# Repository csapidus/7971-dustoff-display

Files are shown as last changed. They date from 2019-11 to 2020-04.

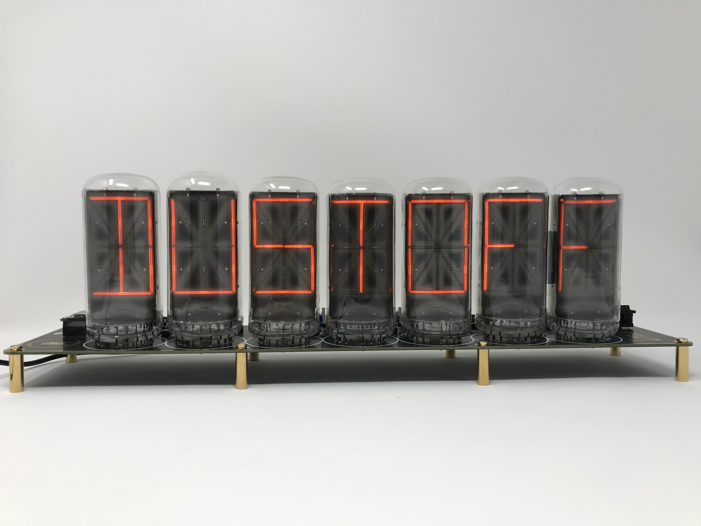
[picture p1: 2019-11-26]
photos/IMG_0761.JPG

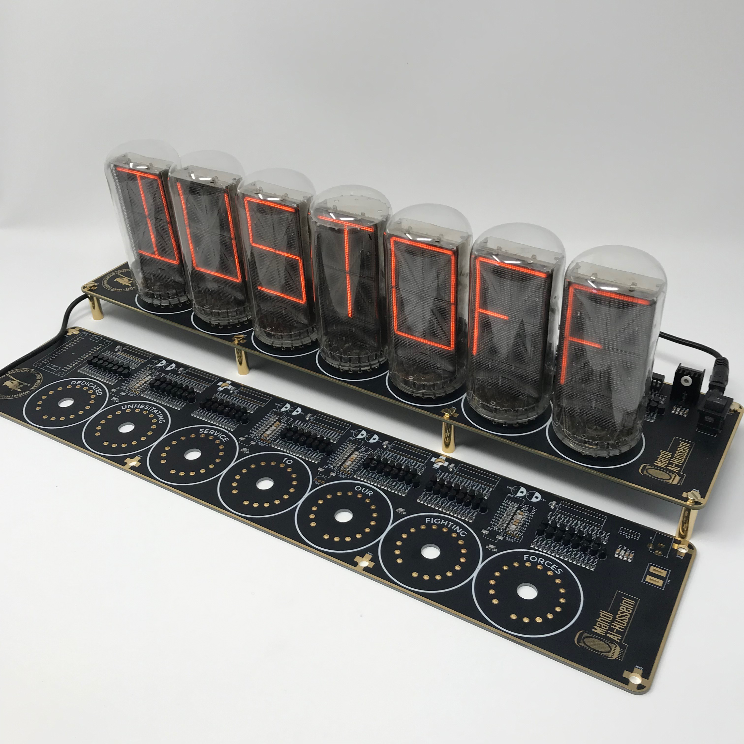
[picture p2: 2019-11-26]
photos/IMG_0769.JPG

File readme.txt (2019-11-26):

Hi!

Thanks for purchasing the B7971 DUSTOFF IoT Board. This folder has documentation to include schematics, footprints, code for both the PICs and the 8266, and various photos and logos. If there is something you would like added, please message me at mahdi07@msn.com, and I will do my best to fulfill the request. 

Special thanks to Frantisek Skorsepa, who provided the HVPS design, and to Chris Barron* (aka fixitsan2) who developed the B7971 SmartSocket circuit. Without the support of these two, this project would have taken significantly longer to complete. 

v/r,

Mahdi

* from Chris *
Revised May 2008
Permission is granted for any person to use the information in these files to
construct devices of any nature which use this software as long as that device
is not harmful to life of any sort, and with the condition that if you go on to
publicise your work you should  include either a link to the Smart Sockets group
or mention me as the author of the original software.

Should you feel you have benefitted from using them, or had some fun playing with
them, and if that makes you feel that you want to give something back, please
consider sending a small donation to Engineer Aid, their website details are
http://www.engineeraid.com/

Thank you

Chris Barron

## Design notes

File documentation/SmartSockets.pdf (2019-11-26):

# Smart Sockets

Through the use of simple ASCII type instructions it is possible to use this device to produce arrays of many display devices, of similar and different types. The device features 8 built in numerical fonts, 2 special fonts for use with nixie tubes and bargraph displays, and 10 transition effects. The standard Burroughs alphanumeric font is pre-programmed and in addition to this there are 124 user definable characters. The industry standard 9600 Baud, 8 data bits, No parity,1 stop bit , 8N1, protocol enables almost any computer, handheld PDA, or microcontroller to communicate with the display elements directly, allowing for rapid development, and enabling some complex display routines to be generated from very simple commands.

# General Information

It is not unusual to want to generate complex display routines, only to find that you run out of memory, or have reached limits of performance of the controlling devices such that progress is hampered and compromises have to be made.

The idea behind this device came from a need to generate complex display routines through the use of a microcontroller. Having good programming skills is usually an advantage in such situations but even then it can become difficult to make a display which can respond to variable data in addition to the host performing the other functions which it has been assigned to do.

From a hardware point of view it is also convenient to mount all of the driving components on the same board as the B7971. With the exception of the power supply and data lines, there are no other connections required to make these boards produce the type of display which meets the modern expectations of complexity and visual interest. Each cathode has its own current limiting resistor fitted, in accordance with the original Burroughs recommended best practice. This means that a constant light output is guaranteed from each segment to make a uniform display regardless of how many segments are illuminated.

The ‘smart’ aspect of the device comes from the way in which each socket communicates with its neighbour in order to establish its own position in the display array. This means that if you send an ascii text string such as ‘ NIXIE ’ to a display array of 5 sockets each character is displayed on the correct display with respect to it’s position in the text string. So the first tube displays the ‘N’ , the next tube the ‘I’, and so on……

A flexible data input format allows for the characters, fonts, effects and the speed of those effects to be changed in ways which suit different programming constructs and the different types of terminal programs which can be used to control the sockets.

# The Instruction Set

Instructions are always sent to the first socket in an array. Each socket in turn resends the instructions to the following socket and extracts any useful information intended for itself. Each socket is aware of its position in an array such that it can calculate which character in a string of characters is to be interpreted

All instructions take the following form -

< 3 Character Header > + < Single Character Command > + < Command Values > + < ENTER >

The header and the command characters must all be in upper case. (Replace ‘<ENTER>’ with ascii character 13 where necessary.)

The three character header is always = $B7, which allows the sockets to be connected to an existing data bus with minimal risk of it being affected by an existing flow of data . Message validity is checked upon the receipt of the final <ENTER>.

### COMMANDS

There are two types of commands. Display commands and resource commands.

### DISPLAY COMMAND

M Group message string

### RESOURCE COMMANDS

F Set individual fonts
E Set individual effects
S Set individual effect speeds
W Write a bit pattern to an eeprom location to create a user defined character U Set the underscore segment on or off at any position in the array

### Group Message String Command

The group message command is the most common message in most cases. With this command you are transmitting the actual display data to the array of display devices.

FORMAT = $B7Mxxxxxxxx <ENTER> (where xxxxxx is the string to display)

For example, if you wish to display the string ‘ NIXIE’ across the array then send the following command: $B7MNIXIE <enter> : Note there are no spaces or comma’s.

### The Null Character ‘!’

An important character is the exclamation mark “ ! “
When this character is used in a command it is interpreted as ‘no instruction’ to the socket of the same relative position as the null character has in the string. This is useful in a message because you can send an instruction that only changes one character and leaves the existing display unchanged. For example, to set the character in the 4th position to the letter ‘S’ and leave the rest of the display untouched use the following command.

$ B 7 M ! ! ! S ! ! ! ! ! ! ! <ENTER>

The null character can also be used in the resource commands for Font, Effect and Speed.

### The Resource Command Structures

Resource commands are a useful way to set the fonts, effects and the speed of the effect used at the next transition. The current display is not altered during the programming of effects, fonts and speeds, which allows them to be sent ‘silently’ in the background. Even if a transition or effect is in progress the new resource commands will still be received and the new values stored for the next transition. A different font can be assigned to each position in the array, should it be desired. Also, different transition effects and effect speeds can be run in any character position

### F Set individual fonts

FORMAT = $B7Fxxxxxx<ENTER>
Where xxxxxx are the new fonts to be used, relative to their position in the display array. Valid font numbers are 0 to 9 and ‘ U ‘

EG: To change the fonts of the first and third tubes to font 3, and all other positions to font 1 the command to send is $B7F313111<ENTER>

### E Set individual effects

FORMAT = $B7Exxxxxx<ENTER>
Where xxxxxx are the numbers of the new effects, relative to their position in the display array. Valid effect numbers are 0 to 9

EG: To change the effects of the second and fourth positions to 5 and all other positions to effect 2 the command is $B7E252522<ENTER>

### S Set individual effect speeds

FORMAT = $B7Sxxxxxx<ENTER> Where xxxxx are the new effect speeds, position dependant. Valid Speed Number values are 0 to 9
This command structure works in the same way as $B7F and $B7E above.

### U Set the underscore segment on or off at any position in the array

$B7U xxx1xx0xx<ENTER> Where 1 = underscore on in that position, 0 turns off the underscore for that position, and ‘x’ can be any other character. Onl;y 0’s and 1’s are responded to when the underscore command has been sent.

Underscores are not turned on immediately but their requested status either on or off is remembered for the next time a character change command is sent to the same position. For example , sending $B7U1!!!!! will instruct the socket to turn on the underscore at position 1at the next character transition, so afterwards if you send $B7M8, then the first position will display the character ‘8’ and the underscore will come on at the same time

The underscore inherits the transition effect in use for the characters.

Where there is a user defined character being displayed which makes use of the underscore, any instructions to set or clear the underscore are ignored.

The null character can be used with fonts and effects just as in the same way as it is used in character messages. In this way a new command can be transmitted by the host controller without it needing to have remembered the current settings in order to overwrite them correctly.

EG, to change the font in position four to font number eight, leaving all other fonts unchanged…….

$ B 7 F ! ! ! 8 ! ! ! ! ! <ENTER>

### W Write a bit pattern to eeprom memory to create a user defined character, (UDC)

The characters which can be redefined are stored in an area of eeprom reserved specifically for the user, in no way can making changes to the UDC’s affect program operation or affect the built in fonts, which makes dealing with UDC’s a very safe practice. The use of eeprom memory means that the UDC’s are retained after a power failure.
The characters which can be redefined are assigned to ascii characters which are easily referenced by using their character symbol, either directly from the keyboard of your terminal device, or by sending the ascii character value from the controlling device.

FORMAT = $B7Wcbbbbbbbbbbbbbbb<ENTER>

Where c = the ascii character to be reprogrammed and bbbbbbbbbbbbbb is the bit pattern to use to make the new character.

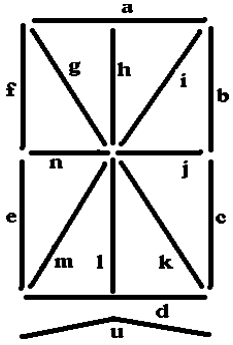
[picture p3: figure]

The segments of the B7971 and ZM1350 are denoted by letters. The group of letters ‘bbbbbbbbbbbbbbb’ in the command refers to the segments in the following order abcdefghijklmnu. (where ’ u ’ is the underscore).

Once you have designed the new character, by entering the assignment of the segments into the corresponding position they occupy in the command, where a ‘1’ denotes an on cathode and a ‘0’ denotes an off cathode segment, the new character will be stored.

Example Showing The Writing of a UDC Bit Pattern
To produce a character which is made up from segments a,b,c,d and j.
And to store this new character in the location currently assigned to the character ‘c’, the command to produce this change is

$B7Wc111100000100000<ENTER>

In order to make use of the new character include it into a display command string, referring to it by its original ascii definition, in this case ‘c’. It is important to note that the font which is assigned to the user defined characters does not have a number, but a single letter, the letter ’U’ (in uppercase). So for example, to display this new character on position 4 tube we first need to set the number 4 position to display the UDC

$ B 7 F ! ! ! U ! ! ! ! <ENTER>

And now to display it
$ B 7 M ! ! ! c ! ! ! ! ! <ENTER>

Where c= the character and U = user defined character font

## The User Definable Characters

Characters which can be redefined are shown below. It is important to note that programming the UDCs does not affect the inbuilt text font, which remains available when any font number 0-9 is selected With the exception of Char 13, and the “!” sign, all characters from 0-58 can also be reprogrammed.

# Initial UDC Settings

Some UDC Characters have already been programmed. These characters
can be overwritten as required.
Code | | Set | Code | | Set | Code | | Set | Code | | Set | Code | | Set
58 | : | | 59 | ; | | 60 | < | | 61 | = | | 62 | >
63 | ? | | 64 | @ | | 65 | A | | 66 | B | | 67 | C
68 | D | | 69 | E | | 70 | F | | 71 | G | | 72 | H
73 | I | | 74 | J | | 75 | K | | 76 | L
Ascii Code | Char acter | Ascii Code | Char acter | Ascii Code | Char acter | Ascii Code | Char acter | Ascii Code | Char acter | Ascii Code | Char acter | Ascii Code | Char acter | Ascii Code | Char acter
58 | : | 59 | ; | 60 | < | 61 | - | 62 | > | 63 | ? | 64 | @ | 65 | A
66 | B | 67 | C | 68 | D | 69 | E | 70 | F | 71 | G | 72 | H | 73 | I
74 | J | 75 | K | 76 | L | 77 | M | 78 | N | 79 | O | 80 | P | 81 | Q
82 | R | 83 | S | 84 | T | 85 | U | 86 | V | 87 | W | 88 | X | 89 | Y
90 | Z | 91 | [ | 92 | \ | 93 | ] | 94 | ^ | 95 | _ | 96 | - | 97 | a
98 | b | 99 | c | 100 | d | 101 | e | 102 | f | 103 | g | 104 | h | 105 | i
106 | j | 107 | k | 108 | l | 109 | m | 110 | n | 111 | o | 112 | p | 113 | q
114 | r | 115 | s | 116 | t | 117 | u | 118 | v | 119 | w | 120 | x | 121 | y
122 | z | 123 | { | 124 | | | 125 | } | 126 | ~

## Data format information

Data Rate
9600bps

Data Bits
8

Parity
N

Stop Bits
1

Flow Control
None

The default data level is TTL compatible and makes driving arrays of sockets with a microcontroller a very simple task. If you wish to use a PC, or any other device that transmits RS232 data levels the use of a level shifter is recommended. One of the most common is the MAX232 device. Many equivalents are also available. The MAX233 does not require the use of additional capacitors at all, which is a bonus, and the MAX232A requires you to use only 4 capacitors with a value of 0.1uF. You do not need to use a MAX232 or equivalent, a simple level shift arrangement can be achieved using the following circuit.

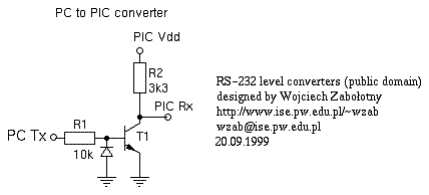
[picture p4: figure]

## The Fonts

0 = Seven Segment – Standard Seven Segment Display Font
1 = Burroughs Fourteen Segment – Standard 14 Segment Display Font 2 = Leaning – Numbers an Italic Emphasis
3 = Formal – Digits Which Might Appear Somewhere Important
4 = Chamfer – A Font For Carpenters and Structural Engineers
5 = Secret – Lean Your Head Over To The Left
6 = Caitlin – My Daughter’s Hard Work, Proving Fontmaking is Childsplay 7 = Clockalogue – When Incremented Sequentially The Time Ticks By 8 = Linear Bargraph – The Number of Lights Lit Increases
9 = Nixie – Standard 0 to 9 Independent Cathode Drive
U = User Defined Characters

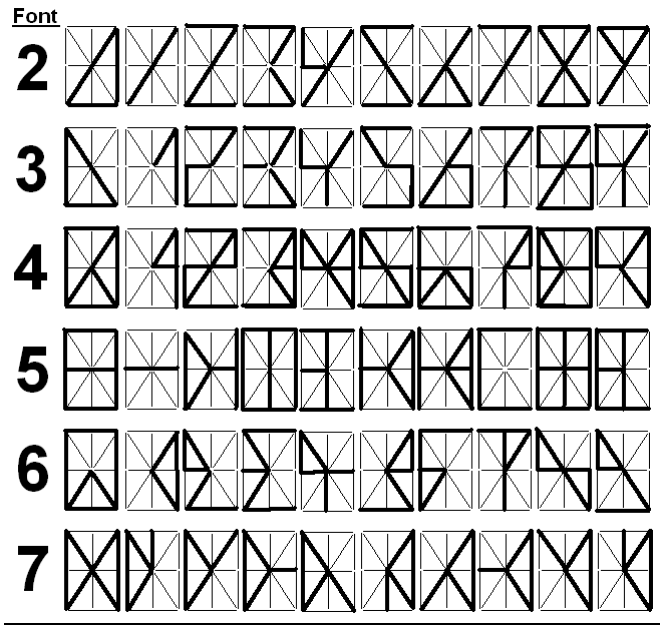
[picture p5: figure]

## The Effects

0 = No effect, instant change
1 = Cross-fade
2 = Jump Fade (instant on, fade out)
3 = Fade out, fade in
4 = Zipper, bilateral downward wipe and refresh 5 = Shifter, characters wiped left to right *
6 = Segment deconstruction and rebuild
7 = Spin, half cycle
8 = Spin, full cycle
9 = Radar

*Used sequentially this can give the effect of a wipe across all tubes starting at the left and moving to the right

## Advanced Use

With some clever programming, it would be possible for the host controller to properly parse the string being sent so that it will fit on the display correctly without overflowing. In order to do this the host will need to know how many display elements or smart sockets make up the display array. It is possible for the host to read the value being transmitted by the last socket in the array at startup. Doing this will provide a binary value of the number of sockets in the array. At startup the first socket assigns a value of 1 to itself and
communicates with its downstream neighbour such that the next socket in line calls itself number 2…and so on down the line. This only happens once during each startup cycle, within 100mS of power being applied.

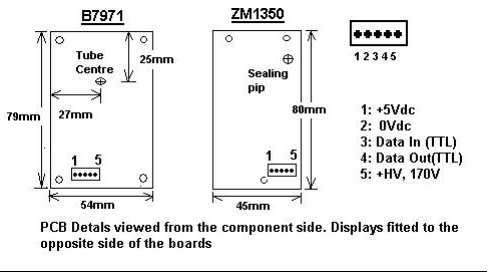
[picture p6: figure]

Details of a typical wiring harness layout

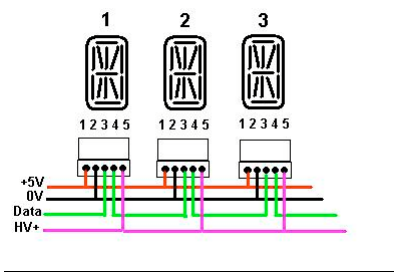
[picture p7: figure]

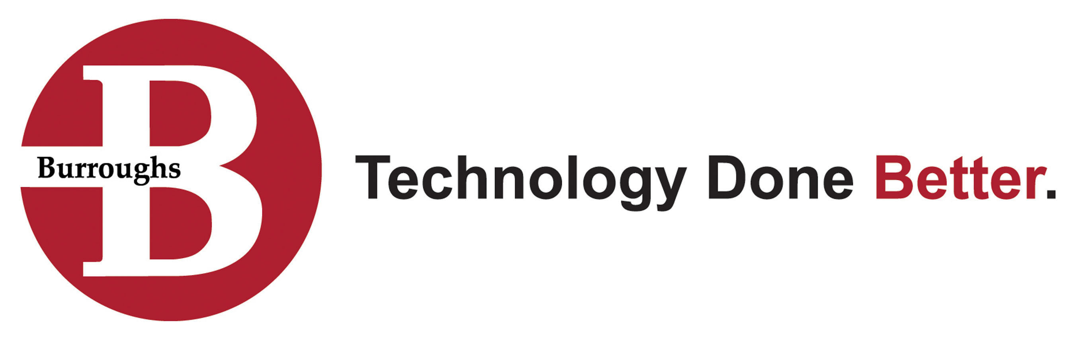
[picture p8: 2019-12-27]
documentation/burroughs.jpg

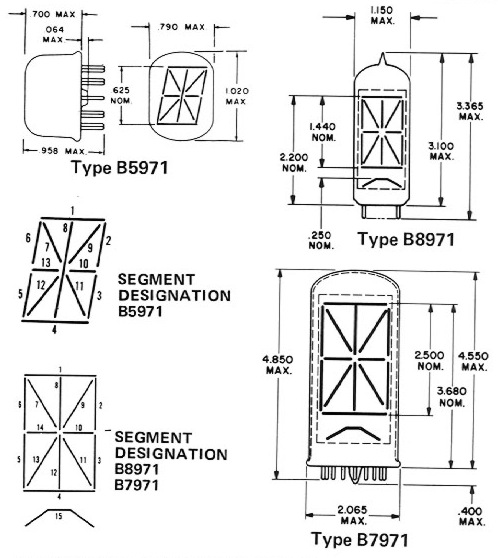
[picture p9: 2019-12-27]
documentation/B7971_dimensions.jpg

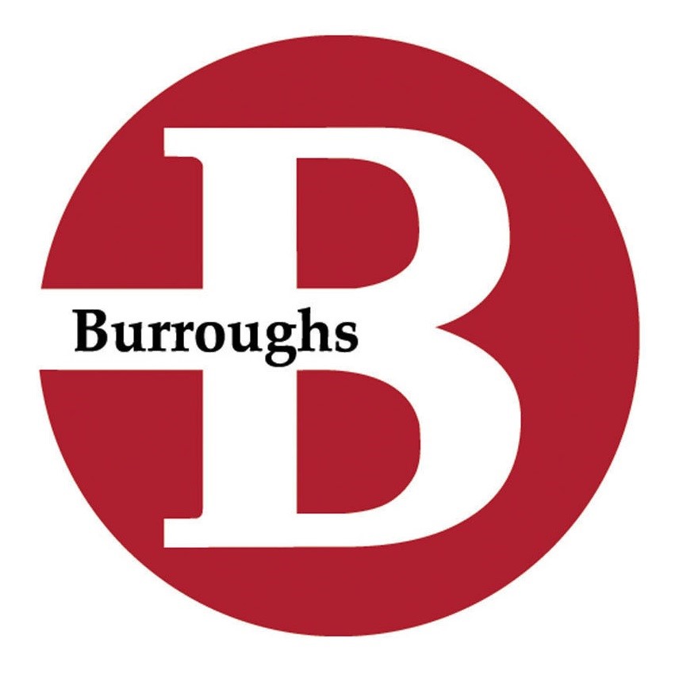
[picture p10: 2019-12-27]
documentation/burroughs_small.jpg

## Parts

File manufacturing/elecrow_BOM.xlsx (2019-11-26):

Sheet: BOM template
BOM template
NO | Designator | Quantity | Part Number（MPN）Very important | Description | Value | Package | Comment or Link
1 | R2 R3 R7 R8 R32 R33 R37 R38 R62 R63 R67 R68 R92 R93 R97 R98 R122 R123 R127 R128 R152 R153 R157 R158 R182 R183 R187 R188 | 28 | RC1206FR-0724KL |  | 24K | 1206
2 | R4 R9 R10 R11 R12 R13 R14 R15 R16 R19 R24 R25 R26 R27 R28 R29 R30 R34 R39 R40 R41 R42 R43 R44 R45 R46 R49 R54 R55 R56 R57 R58 R59 R60 R64 R69 R70 R71 R72 R73 R74 R75 R76 R79 R84 R85 R86 R87 R88 R89 R90 R94 R99 R100 R101 R102 R103 R104 R105 R106 R109 R114 R115 R116 R117 R118 R119 R120 R124 R129 R130 R131 R132 R133 R134 R135 R136 R139 R144 R145 R146 R147 R148 R149 R150 R154 R159 R160 R161 R162 R163 R164 R165 R166 R169 R174 R175 R176 R177 R178 R179 R180 R184 R189 R190 R191 R192 R193 R194 R195 R196 R199 R204 R205 R206 R207 R208 R209 R210 | 119 | RC1206FR-0733KL |  | 33K | 1206
3 | R5 R6 R17 R20 R21 R31 R35 R36 R47 R50 R51 R61 R65 R66 R77 R80 R81 R91 R95 R96 R107 R110 R111 R121 R125 R126 R137 R140 R141 R151 R155 R156 R167 R170 R171 R181 R185 R186 R197 R200 R201 R211 | 42 | RC1206FR-0727KL |  | 27K | 1206
4 | R18 R22 R23 R48 R52 R53 R78 R82 R83 R108 R112 R113 R138 R142 R143 R168 R172 R173 R198 R202 R203 | 21 | RC1206FR-0722KL |  | 22K | 1206
5 | R212 R220 R221 R229 R230 R238 R269 R277 | 8 | RC1206FR-07100RL |  | 100R | 1206
6 | R213 R222 R231 R270 | 4 | RC1206FR-0722RL |  | 22R | 1206
7 | R214 R223 R232 R271 | 4 | RC1206FR-07220KL |  | 220K | 1206
8 | R215 R224 R233 R272 | 4 | RC1206FR-072K7L |  | 2.7K | 1206
9 | R216 R218 R225 R227 R234 R236 R273 R275 | 8 | RCWE1206R100FKEA |  | 0.1R | 1206
10 | R217 R226 R235 R274 | 4 | RC1206FR-07120KL |  | 120K | 1206
11 | R219 R228 R237 R276 | 4 | RC1206FR-07270KL |  | 270K | 1206
12 | C3 C4 C6 C7 C8 C11 C13 C17 C23 C27 C33 C37 C43 C47 | 14 | C1206X105K5RECAUTO |  | 1uF | 1206
13 | C10 C1 C2 C5 C52 C53 C54 C55, C12 C18 C20 C22 C28 C30 C32 C38 C40 C42 C48 C50 | 20 | C1206C104J3GECAUTO |  | 0.1uF | 1206
14 | C9 | 1 | C1206F334K1RACTU |  | 0.33uF | 1206
16 | C14 C19 C24 C29 C34 C39 C44 C49 | 8 | C1206C822JCGACAUTO |  | 8.2nF | 1206
17 | Q11 Q1 Q2 Q3 Q4 Q5 Q6 Q7 Q8 Q9 Q10 Q12 Q13 Q14 Q15 Q16 Q17 Q18 Q19 Q20 Q21 Q22 Q23 Q24 Q25 Q26 Q27 Q28 Q29 Q30 Q31 Q32 Q33 Q34 Q35 Q36 Q37 Q38 Q39 Q40 Q41 Q42 Q43 Q44 Q45 Q46 Q47 Q48 Q49 Q50 Q51 Q52 Q53 Q54 Q55 Q56 Q57 Q58 Q59 Q60 Q61 Q62 Q63 Q64 Q65 Q66 Q67 Q68 Q69 Q70 Q71 Q72 Q73 Q74 Q75 Q76 Q77 Q78 Q79 Q80 Q81 Q82 Q83 Q84 Q85 Q86 Q87 Q88 Q89 Q90 Q91 Q92 Q93 Q94 Q95 Q96 Q97 Q98 Q99 Q100 Q101 Q102 Q103 Q104 Q105 | 105 | MPSA42 | MPSA42 |  | TO-92
18 | D1, D2, D3, D4 | 4 | MBR2H200SFT3G | DIODE SCHOTTKY 200V 2A SOD123
19 | U3, U4, U5, U6, U7, U8, U9 | 7 | 110-43-320-41-001000 | CONN IC DIP SOCKET 20POS GOLD
20 | U10, U11, U12, U14 | 4 | LM3478MAX/NOPB | IC REG CTRLR MULT TOPOLOGY 8SOIC
21 | C16, C26, C36, C46 | 4 | C1206C474K3RACTU |  | 470nF | 1206
22 | B1, B2, B3, B4, B5, B6, B7 | 119 | H3161-01 | CONN PIN RCPT .035-.041 KNURL
23 | L1, L2, L3, L4 | 4 | 744777920 | FIXED IND 100UH 790MA 380 MOHM | 100UH
SUM |  | 532

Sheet: Sheet1
12;"J1";"BarrelJack_Horizontal";1;"Barrel_Jack_Switch";;;
13;"Q106 | Q107 | Q108 | Q124";"TO-220-3_Vertical";4;"IRF640";;;
14;"R2 | R3 | R7 | R8 | R32 | R33 | R37 | R38 | R62 | R63 | R67 | R68 | R92 | R93 | R97 | R98 | R122 | R123 | R127 | R128 | R152 | R153 | R157 | R158 | R182 | R183 | R187 | R188";"R_1206_3216Metric_Pad1.42x1.75mm_HandSolder";28;"24K";;;
15;"R4 | R9 | R10 | R11 | R12 | R13 | R14 | R15 | R16 | R19 | R24 | R25 | R26 | R27 | R28 | R29 | R30 | R34 | R39 | R40 | R41 | R42 | R43 | R44 | R45 | R46 | R49 | R54 | R55 | R56 | R57 | R58 | R59 | R60 | R64 | R69 | R70 | R71 | R72 | R73 | R74 | R75 | R76 | R79 | R84 | R85 | R86 | R87 | R88 | R89 | R90 | R94 | R99 | R100 | R101 | R102 | R103 | R104 | R105 | R106
16;"R5 | R6 | R17 | R20 | R21 | R31 | R35 | R36 | R47 | R50 | R51 | R61 | R65 | R66 | R77 | R80 | R81 | R91 | R95 | R96 | R107 | R110 | R111 | R121 | R125 | R126 | R137 | R140 | R141 | R151 | R155 | R156 | R167 | R170 | R171 | R181 | R185 | R186 | R197 | R200 | R201 | R211";"R_1206_3216Metric_Pad1.42x1.75mm_HandSolder";42;"27K";;;
17;"R18 | R22 | R23 | R48 | R52 | R53 | R78 | R82 | R83 | R108 | R112 | R113 | R138 | R142 | R143 | R168 | R172 | R173 | R198 | R202 | R203";"R_1206_3216Metric_Pad1.42x1.75mm_HandSolder";21;"22K";;;
 | R3
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

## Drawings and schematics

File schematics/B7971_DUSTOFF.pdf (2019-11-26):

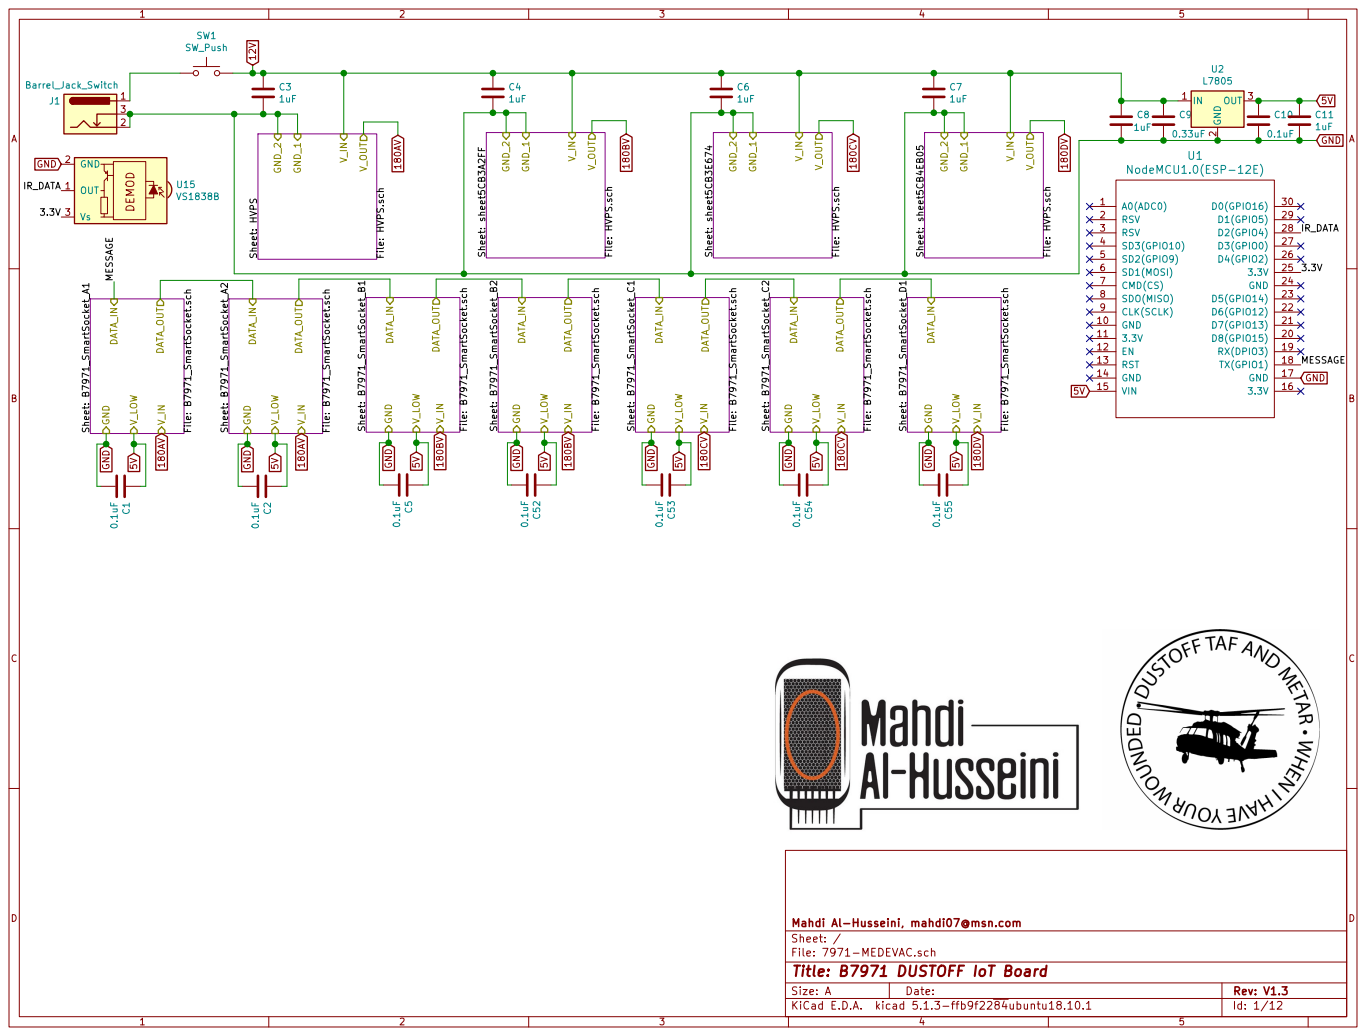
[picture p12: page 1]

Id: 1/12 Title: B7971 DUSTOFF IoT Board

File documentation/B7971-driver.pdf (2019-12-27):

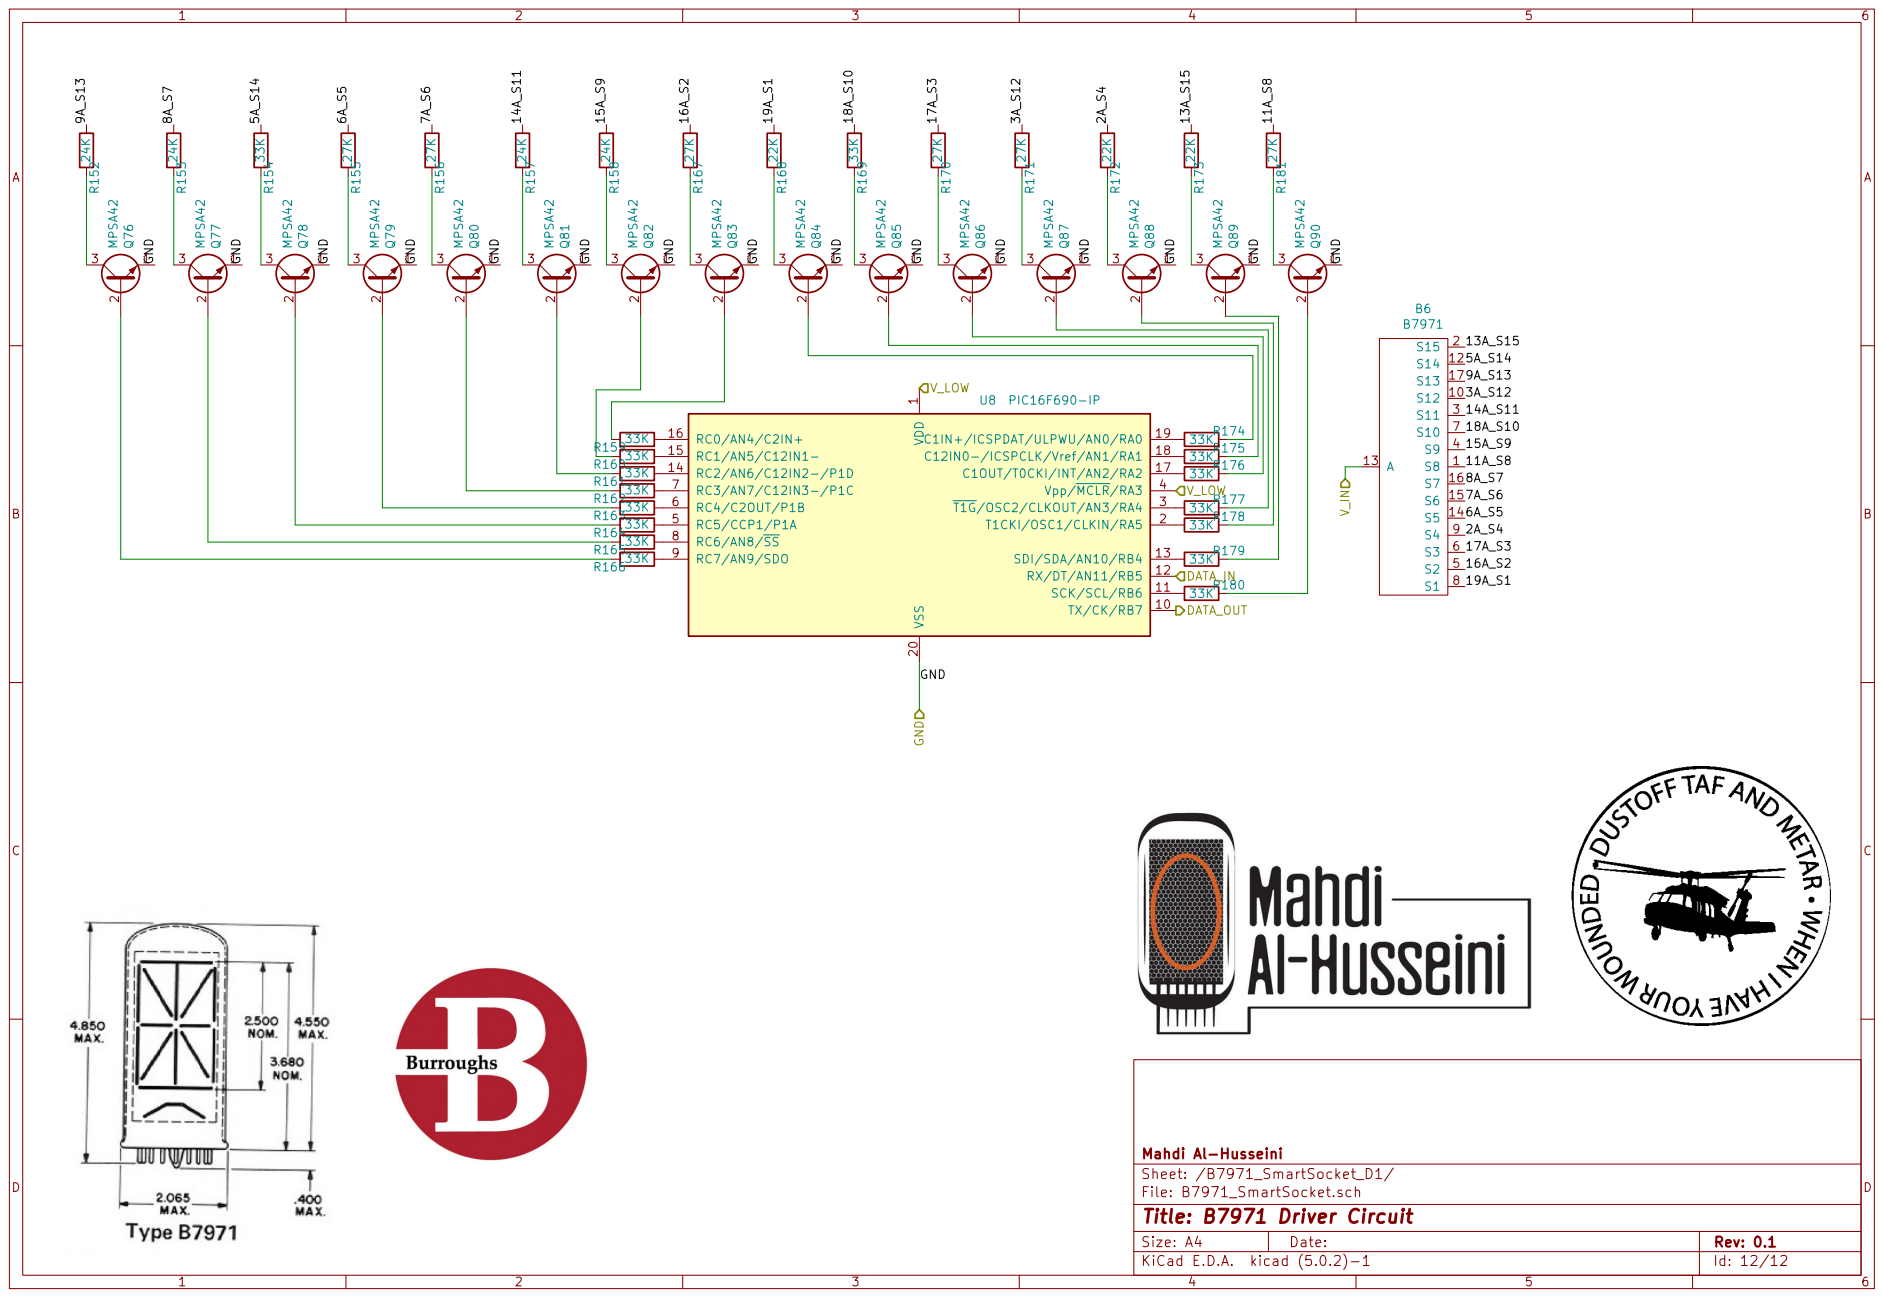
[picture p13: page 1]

1 TX/CK/RB7 10 SCK/SCL/RB6 11 RX/DT/AN11/RB5 12 SDI/SDA/AN10/RB4 13 RC2/AN6/C12IN2-/P1D 14 RC1/AN5/C12IN1- 15 RC0/AN4/C2IN+ 16 C1OUT/T0CKI/INT/AN2/RA2 17 C12IN0-/ICSPCLK/Vref/AN1/RA1 18 C1IN+/ICSPDAT/ULPWU/AN0/RA0 19 T1CKI/OSC1/CLKIN/RA5 2 VSS 20 T1G/OSC2/CLKOUT/AN3/RA4 3 Vpp/MCLR/RA3 4 RC5/CCP1/P1A 5 RC4/C2OUT/P1B 6 RC3/AN7/C12IN3-/P1C 7 RC6/AN8/SS 8 RC7/AN9/SDO 9 U8 PIC16F690-IP R175 33K R174 33K R178 33K R176 33K R179 33K R180 33K R159 33K R160 33K R161 33K R162 33K R163 33K R164 33K R165 33K R166 33K R177 33K

Sheet: /B7971_SmartSocket_D1/ Mahdi Al-Husseini VDD

File: B7971_SmartSocket.sch
Id: 12/12 Title: B7971 Driver Circuit

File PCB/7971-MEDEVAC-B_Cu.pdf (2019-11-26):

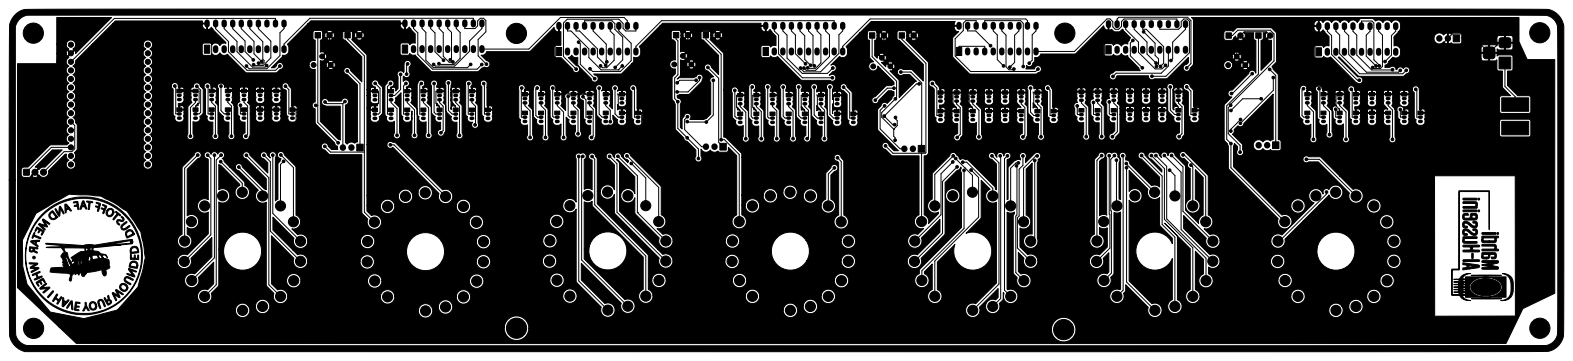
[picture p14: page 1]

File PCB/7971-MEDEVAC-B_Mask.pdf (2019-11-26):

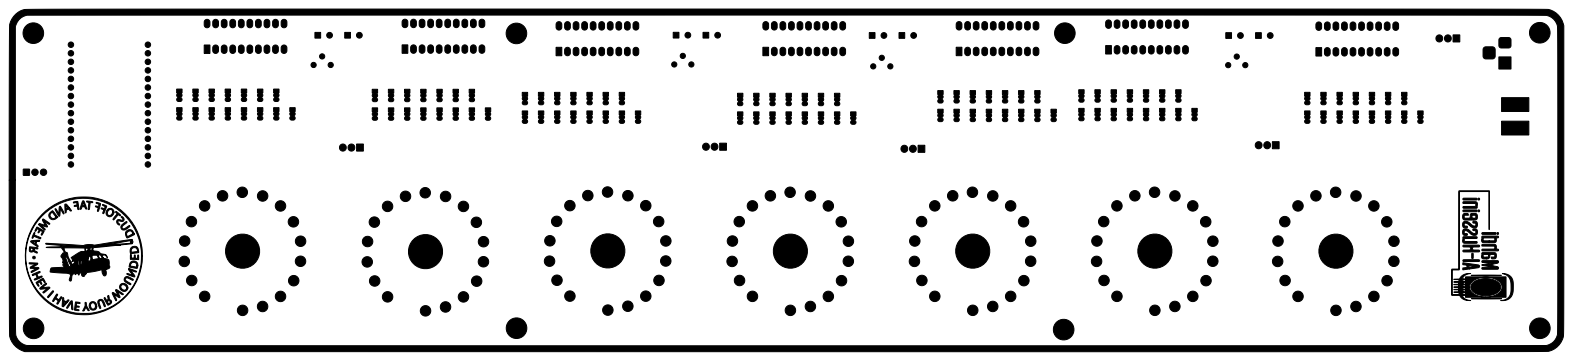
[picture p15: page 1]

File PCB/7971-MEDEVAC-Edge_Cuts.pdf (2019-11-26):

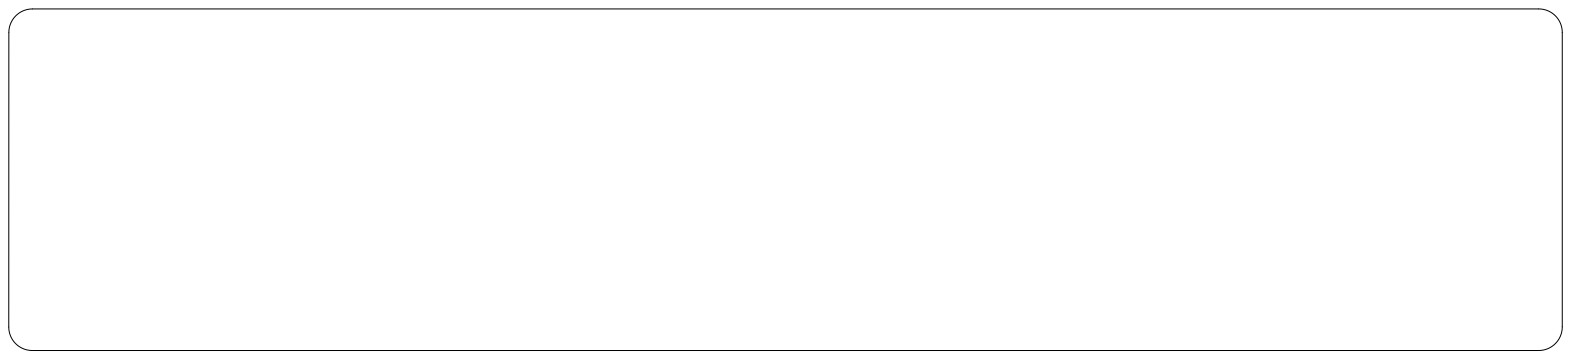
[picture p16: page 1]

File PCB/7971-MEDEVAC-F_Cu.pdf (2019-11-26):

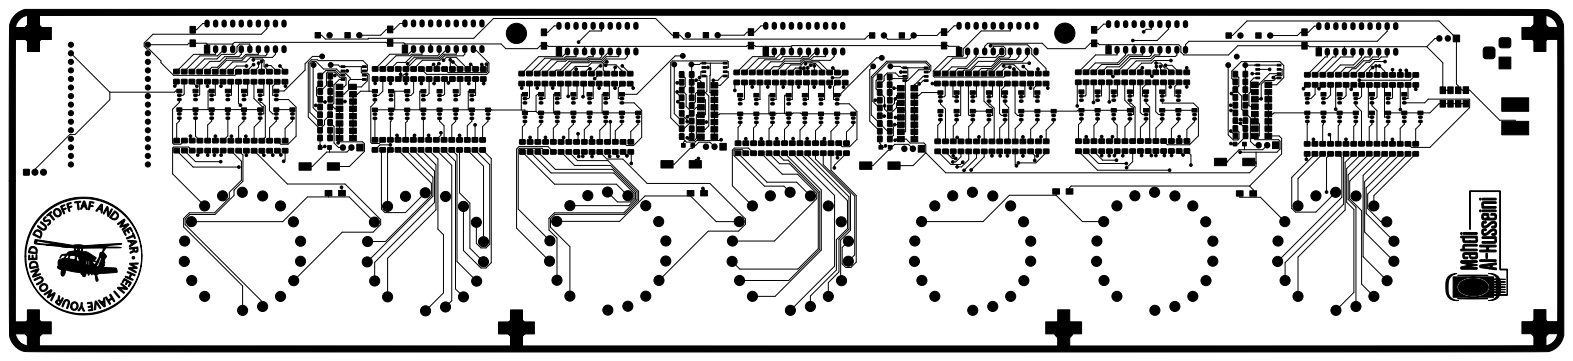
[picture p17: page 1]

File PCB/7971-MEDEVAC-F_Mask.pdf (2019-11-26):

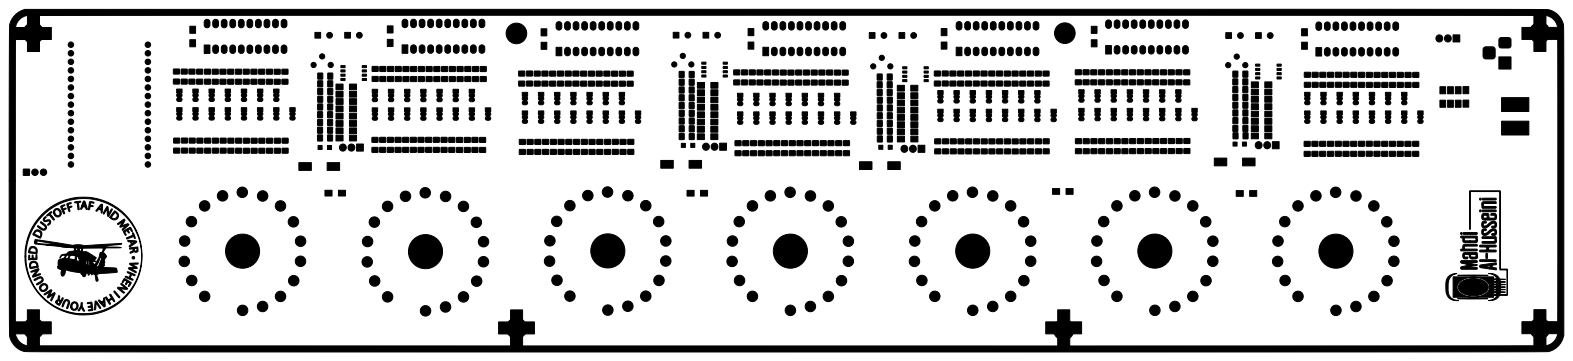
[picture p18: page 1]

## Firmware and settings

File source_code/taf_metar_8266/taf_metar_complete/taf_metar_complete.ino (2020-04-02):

/*  B7971 DUSTOFF IoT BOARD 
 *  Date Modified: 2 Apr 2020
 *  Developer: Mahdi Al-Husseini, mahdi07@msn.com
 *  mahdialhusseini.com
 *  
 *  Note: This project uses an Espressif 8266 NodeMCU LUA uC board, allowing for internet connectivity. 
 *  It is required you set the ssid and password variables appropriately, and your lon and lat if intending on using METAR/TAF (for now).
 *  License (Beerware): This code is open to the public but you buy me a beer if you use this and we meet someday
 */

#include <ESP8266WiFi.h>  // standard 8266 WiFi connectivity (https://arduino-esp8266.readthedocs.io/en/latest/esp8266wifi/readme.html)
#include <WiFiClientSecure.h>  // supports secure connections using TLS (SSL) (https://github.com/espressif/arduino-esp32/tree/master/libraries/WiFiClientSecure)
#include <WiFiUdp.h> // allows for sending and recieving UDP packets (https://www.arduino.cc/en/Reference/WiFiUDPConstructor)

/* IR package for 8266. Contributors: https://github.com/crankyoldgit/IRremoteESP8266/blob/master/.github/Contributors.md */
#include <IRrecv.h> //
#include <IRremoteESP8266.h> // https://github.com/crankyoldgit/IRremoteESP8266
#include <IRutils.h>

/* For SparkFun IR Remote */ 
const uint16_t BUTTON_POWER = 0x629D;
const uint16_t BUTTON_A = 0x22DD;
const uint16_t BUTTON_B = 0x02FD;
const uint16_t BUTTON_C = 0xC23D;
const uint16_t BUTTON_UP = 0x9867;
const uint16_t BUTTON_DOWN = 0x38C7;
const uint16_t BUTTON_LEFT = 0x30CF;
const uint16_t BUTTON_RIGHT = 0x7A85;
const uint16_t BUTTON_CIRCLE = 0x18E7;

IRrecv irrecv(4); // Receive on pin 4
decode_results results;
uint16_t lastCode = 0; // This keeps track of the last code RX'd

/* WiFi */
const char* ssid = "SSID";
const char* password = "PW";

/* National Weather Service (NWS) API */
const char* host = "www.aviationweather.gov";

// Your current location; adjust as needed. This is currently hardcoded, but an update in the future will allow automatic triangulation of the 8266 location using LocationAPI from Unwired Labs.
String lon = "43.738328";
String lat = "-83.707237";

/* TAF is Terminal Aerodrome Forecast: https://en.wikipedia.org/wiki/Terminal_aerodrome_forecast
 * METAR is Meteorological Terminal Aviation Routine [Weather Report]: https://en.wikipedia.org/wiki/METAR
 * Guidance for designing url_METAR requests: https://www.aviationweather.gov/dataserver/example?datatype=metar 
 * Guidance for designing url_TAF requests: https://www.aviationweather.gov/dataserver/example?datatype=metar 
 * url_METAR: currently set to retrieve the most recent METAR in the past three hours within 20 statue miles
 * url_TAF: currently set to retrieve the most recent RAF in the past three hours within 20 statue miles
 */
 
String url_METAR = "/adds/dataserver_current/httpparam?dataSource=metars&requestType=retrieve&format=xml&radialDistance=20;" + lat + "," + lon + "&hoursBeforeNow=3&mostRecent=true&&fields=raw_text";
String url_TAF = "/adds/dataserver_current/httpparam?dataSource=tafs&requestType=retrieve&format=xml&radialDistance=20;" + lat + "," + lon + "&hoursBeforeNow=3&mostRecent=true&&fields=raw_text";
const int httpsPort = 443;
BearSSL::WiFiClientSecure client;

/* Configuration */
int pollDelay = 20000; //time between each retrieval
int retryWifiDelay = 5000;
const int API_TIMEOUT = 10000;

// 7971 Smart Sockets
String submission;
String instance;
String wifi_status;

void setup() {
  Serial.begin(9600);
  irrecv.enableIRIn();  // Start the receiver
  // Serial.begin(115200);
  // {$B7F...}, {$B7E...}, and {$B7S...} are standard configurations for B7971 text display. This can be adjusted as desired; reference the smart_socket guide pdf. 
  Serial.println("$B7F0000000<cr>");
  Serial.println("$B7E0000000<cr>");
  Serial.println("$B7S0000000<cr>");
  // Retain "$B7M" and "<cr>, but replace "MEDEVAC" as desired for start-up display. 
  Serial.println("$B7MMEDEVAC<cr>");
  connectToWifi();
  client.setInsecure();
  client.setTimeout(API_TIMEOUT);
  scroll("Awaiting Instruction");
}

void connectToWifi() {
  //connect to wifi
  // Serial.print("connecting to ");
  // Serial.println(ssid);
  WiFi.mode(WIFI_STA);
  WiFi.begin(ssid, password);
  while (WiFi.status() != WL_CONNECTED) { //WAITING FOR WIFI
    delay(500);
    Serial.print(".");
  }
  // Serial.println("");
  // Serial.println("WiFi connected");
  // Serial.println("IP address: ");
  // Serial.println(WiFi.localIP());
  scroll("Wifi succesfully connected");
}

void getMETAR() {
  scroll("Loading METAR");
  // Use WiFiClientSecure class to create TLS connection
  // Serial.print("Connecting to ");
  // Serial.println(host);
  if (!client.connect(host, httpsPort)) {
    scroll("connection failed");
    delay(retryWifiDelay);
    return;
  }
  
  // Query the API, METAR
  client.print(String("GET ") + url_METAR + " HTTP/1.1\r\n" +
             "Host: " + host + "\r\n" + 
             "Connection: close \r\n\r\n");
  while(!client.available()){ delay(1);}

  // scroll("client available");
  String matchString;
  String matchAppend;

  while(client.available()){
    matchString = client.readStringUntil('\r');
    matchAppend += matchString;
  }

  // Serial.println(matchAppend);

  // PARSING METAR
  int lineEstimated = matchAppend.indexOf("<raw_text>");
  if (lineEstimated == -1) {
    scroll("NO METAR ALTER PARAMETERS");
    delay(retryWifiDelay);
    return;
  }
  int lineStart = lineEstimated + 10; //exclude `<raw_text>`
  int lineEnd = matchAppend.indexOf("</raw_text>");
  String METAR = matchAppend.substring(lineStart, lineEnd);
  // Serial.print("METAR: ");
  // Serial.println(METAR);
  scroll("METAR");
  scroll(METAR);
  
  client.stop();
}

void getTAF() {
  scroll("Loading TAF");
  // Use WiFiClientSecure class to create TLS connection
  // Serial.print("Connecting to ");
  // Serial.println(host);
  if (!client.connect(host, httpsPort)) {
    // Serial.println(" ... connection failed");
    delay(retryWifiDelay);
    return;
  }
  
  // Query the API, TAF
  client.print(String("GET ") + url_TAF + " HTTP/1.1\r\n" +
             "Host: " + host + "\r\n" + 
             "Connection: close \r\n\r\n");
  while(!client.available()){ delay(1);}

  // Serial.println("Client available");
  String matchString;
  String matchAppend;

  while(client.available()){
    matchString = client.readStringUntil('\r');
    matchAppend += matchString;
  }

  // Serial.println(matchAppend);

  // PARSING TAF
  int lineEstimated = matchAppend.indexOf("<raw_text>");
  if (lineEstimated == -1) {
    // Serial.println("NO TAF, ALTER PARAMETERS");
    delay(retryWifiDelay);
    return;
  }
  int lineStart = lineEstimated + 10; //exclude `<raw_text>`
  int lineEnd = matchAppend.indexOf("</raw_text>");
  String TAF = matchAppend.substring(lineStart, lineEnd);
  // Serial.print("TAF: ");
  // Serial.println(TAF);
  scroll("TAF");
  scroll(TAF);
  
  client.stop();
}

void loop() {
   if(irrecv.decode(&results)){ 
    /* read the RX'd IR into a 16-bit variable: */
    uint16_t resultCode = (results.value & 0xFFFF);

    /* The remote will continue to spit out 0xFFFFFFFF if a
     button is held down. If we get 0xFFFFFFF, let's just
     assume the previously pressed button is being held down */
    if (resultCode == 0xFFFF)
      resultCode = lastCode;
    else
      lastCode = resultCode;

    // add additional functionality here, as needed
    if (resultCode == 0x9867) {
      getMETAR();
    } else if (resultCode == 0x38C7){
      getTAF();
    } else if (resultCode == 0x30CF){
      // getScores not developed
      scroll("ESPN Scores ");
    } else if (resultCode == 0x7A85){
      // getStocks not developed
      scroll("Stock Prices ");
    }
    irrecv.resume();
  }
  delay(100);
}

/* Scroll text across B7971s */
void scroll(String data) {
  // Uppercase the input string
  data = "       " + data + "       ";
  data.toUpperCase();
  
  for (int x = 0; x < data.length() - 6; x++) {
    instance = data.substring(x, x+7);
    submission = "$B7M" + instance + "<cr>";
    Serial.println(submission);
    // Adjust delay speed for fast or slow scroll
    delay(350);
  }
}
